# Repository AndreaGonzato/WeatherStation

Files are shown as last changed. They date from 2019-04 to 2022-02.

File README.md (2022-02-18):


# Weather Station
Weather Station is an Arduino project.

## Main Components
 * clock
 * date keeper
 * digital thermometer
 * digital humidity sensor
 * alarm clock
 
## Electronic Components
This is the complete list of all the electronic components that I used for this project:
* [1] Arduino Mega 2560  (you can't use the Arduino Uno because you don't have too many digital pins)
* [1] breadboard (63x10) 
* [1] DHT11 humidity and temperature (digital sensor) 																
	https://www.amazon.it/gp/product/B00L11IISS/ref=ppx_yo_dt_b_asin_title_o06_s00?ie=UTF8&psc=1
* [1] OLED display (128 * 32)  
	https://www.amazon.it/gp/product/B07D9H83R4/ref=ppx_yo_dt_b_asin_title_o05_s00?ie=UTF8&psc=1
* [1] 7-segments display (4 digits, common cathode)
* [2] 7-segments display (1 digit, common cathode)
* [1] passive buzzer  	
	https://www.amazon.it/gp/product/B071DFX4W2/ref=ppx_yo_dt_b_asin_title_o04_s00?ie=UTF8&psc=1
* [3] buttons
* [7] resistors 220 Ohm
* [3] resistors 1k Ohm
* [50/55] Jumper Wires M/M
* [8] Jumper Wires M/F

## Usage
Install these library on your Arduino environment:
* SevSeg  			https://github.com/DeanIsMe/SevSeg
* Adafruit_GFX  	https://github.com/adafruit/Adafruit-GFX-Library
* Adafruit_SSD1306	https://github.com/adafruit/Adafruit_SSD1306
* DHT				https://github.com/adafruit/DHT-sensor-library
* Adafruit_Sensor  	https://github.com/adafruit/Adafruit_Sensor

Open the file Code/Code.ino using Arduino IDE, compile and upload on your Arduino and then connect all the components like the following schema.

Then to controll the weather station/clock you have three buttons and they work like almost every watch.
In this schema the leftmost one is the SET button, in the middle there is the MINUS one and further to the right there is the PLUS one.
To scroll through menus you can press both of them PLUS or MINUS.
For setting a particular activity you need to press a long on the SET button; to deactivate the alarm just press the SET button in the alarm menu.

## Schema
This is one possible schema for this project:
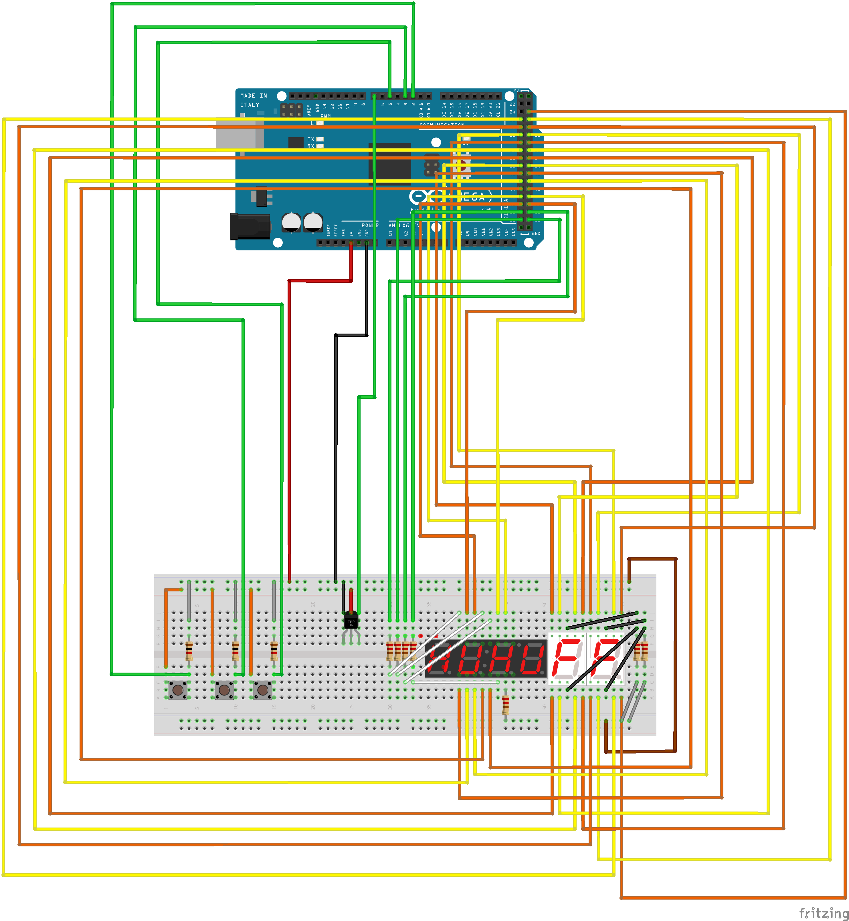
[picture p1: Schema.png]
Scema schema


Note that in this schema there isn't the connection of: passive buzzer and OLED display.
But this two connections are very easy and depends a lot on the components you held.

## Image
This is a photo of my project
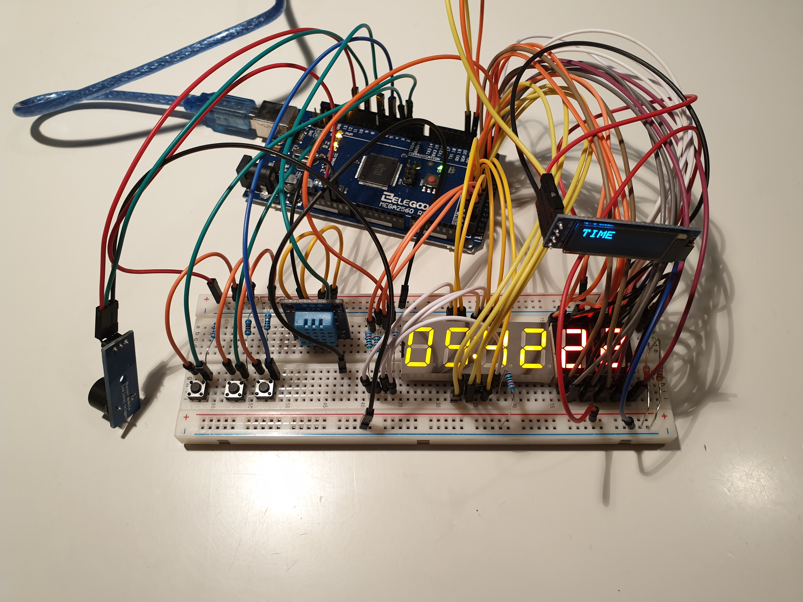
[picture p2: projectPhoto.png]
project photo


## Project Files
**Code** and **Code_No_OOP** folders are two realization of the same project.
If you want all the latest features I recommend to use **Code**.

Last final commit of **Code_No_OOP** was on Apr 18, 2019 and at that time this folder name was "ArduinoCode".

## Hardware & Arduino
The connection protocol used between the display and the Arduino is the I2C.

In Arduino loop function you can't add some delay, because otherwise libraries doesn't work correctly.

The dht11 sensor reads by default the data (temperature and humidity) every 20 seconds. This is to avoid excessive slowdowns to the system.

## Precision
I estimate that the clock loses approximately one second per day.

## Remark
The date format is: dd/mm/yy

## Future developments
The project is not fully completed yet.
Next features to develop:
* new alarm clock melodies
* new timer mode
* new stopwatch mode
* introduction of a barometer sensor and a new mode to read his status 
* introduction of some beep sound during setting mode
* new storage system of weather data on micro sd and a software for having a complete report on PC

## Warnings
The system is not fully tested.

The system after 4,294,967,295 milliseconds ≃ 49 days could crash due to overflow (not tested yet).

## Credits
All the software is open source and developed by Andrea Gonzato

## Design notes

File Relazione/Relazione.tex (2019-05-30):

\documentclass[paper=a4, fontsize=10pt]{scrartcl}

\usepackage{amsmath}
\usepackage[italian]{babel}
\usepackage{tabularx,ragged2e,booktabs,caption} % for table title
\setlength{\parskip}{0.5em} % for paragraph spacing
\DeclareOldFontCommand{\bf}{\normalfont\bfseries}{\mathbf} %declare \bf command in scrartcl

\pagenumbering{gobble} % remove the number of pages

\usepackage{graphicx} % per aggiungere figure/foto

\usepackage{sectsty} % Allows customizing section commands
\allsectionsfont{\normalfont\scshape} % Make all sections, the default font and small caps

%%
\usepackage[utf8]{inputenc}
\newcommand{\approxtext}[1]{\ensuremath{\stackrel{\text{#1}}{\approx}}}
%% now i can add a comment on top of “equal” and “approximate” symbols

\newcommand{\horrule}[1]{\rule{\linewidth}{#1}} % Create horizontal rule command with 1 argument of height

\title{	
\normalfont \normalsize 
\textsc{Universit\`a degli Studi di Trieste - Dipartimento di Ingegneria e Architettura \\ Ingegneria elettronica e informatica - Applicazioni informatiche} \\ [25pt] % Your university, school and/or department name(s)
\horrule{0.5pt} \\[0.4cm] % Thin top horizontal rule
\huge \textbf{Relazione progetto Reti Logiche\\ Weather Station}  \\ % The assignment title
\horrule{2pt} \\[0.5cm] % Thick bottom horizontal rule
}

\author{Andrea Gonzato} % Your name

\date{\normalsize 30 Maggio 2019} % Today's date or a custom date

\setlength{\parindent}{0cm}

\begin{document}
\maketitle % Print the title

\pagebreak

\tableofcontents

\pagebreak

\section{Introduzione}
La relazione riguarda il progetto di Arduino svolto per il corso di reti logiche, tenuto dal professor Marsi dell'Università di Trieste.

\section{Scopo del progetto}
Lo scopo del progetto "Weather Station", come suggerisce il nome, è quello di realizzare una stazione meteorologica amatoriale. L'obiettivo principale è di poter visualizzare la temperatura e l'umidità attuale. Funzionalità secondarie richieste sono: la possibilità di poter leggere l'ora, la data e di poter utilizzare la stazione anche come sveglia. Inoltre è previsto che data, ora e sveglia siano regolabili e che questa sia disattivabile.

\subsection{Descrizione per l'utilizzo}
Per controllare la stazione meteorologica ci sono tre pulsanti: \textit{SET}, \textbf{+}, \textbf{-}.
Il funzionamento ricorda molto l'utilizzo dei classici orologi da polso digitali. Dunque per poter scorrere tutte le funzionalità si utilizzano i pulsanti \textbf{+} e \textbf{-}, mentre per impostare la data, l'ora e la sveglia bisogna tenere premuto, per un secondo, il pulsante \textit{SET}; dopodiché per la regolazione si usano gli analoghi pulsanti,  \textbf{+} e \textbf{-}; invece per passare ad impostare il campo successivo o per attivare/disattivare la sveglia bisogna premere il pulsante \textit{SET} una singola volta.

\subsection{Specifiche}
Il progetto esige come prima specifica che l'orologio non necessiti di una regolazione più di una volta al mese. 
Si richiede quindi la sincronizzazione con un orologio affidabile e dopo 24 ore ci dev'essere una differenza non superiore a un secondo.

La seconda specifica, sui dati meteo, chiede un errore inferiore ad 1 grado Celsius per la temperatura e 2 punti percentuali per l'umidità.

\subsection{Risultato ottenuto}
Nella figura \ref{fig:progettoFoto} si può vedere la realizzazione del progetto completo.

Tutte le specifiche per la realizzazione finale del progetto sono state rispettate.

Nel complesso il sistema si può ritenere funzionante, stabile e facile all'uso.

\begin{figure}
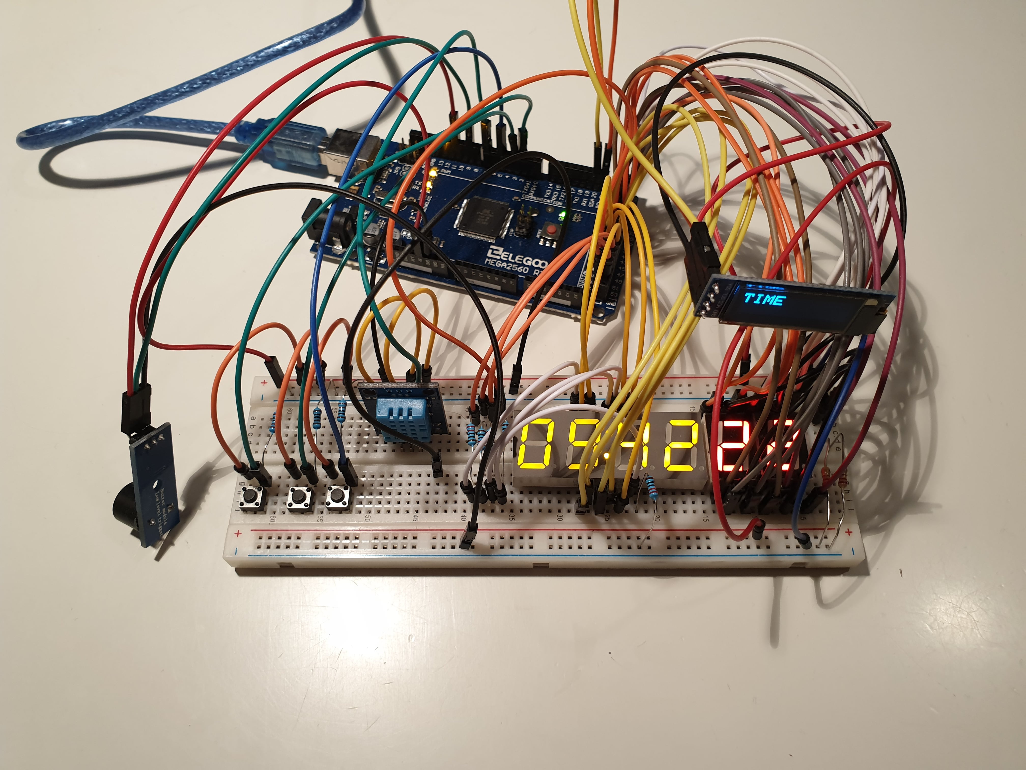
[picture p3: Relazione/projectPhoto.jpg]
  
  \caption{una immagine del progetto}
  \label{fig:progettoFoto}
\end{figure}

\section{Realizzazione}
Il progetto è stato realizzato tra Marzo 2019 e Maggio 2019.\\

\subsection{Metodo usato}
In una prima fase, reperiti i componenti si sono eseguiti una serie di test per comprendere l'utilizzo e le capacità dei singoli.

Nella seconda fase, momento in cui è iniziata la vera realizzazione del progetto, la metodologia adottata si è ispirata al paradigma AGILE. Seguendo questa metodologia si aggiungono funzionalità, una alla volta, passando ciclicamente da una fase di progettazione a una di sviluppo per poi passare ai test e verificare la correttezza delle implementazioni eseguite.

\begin{figure}
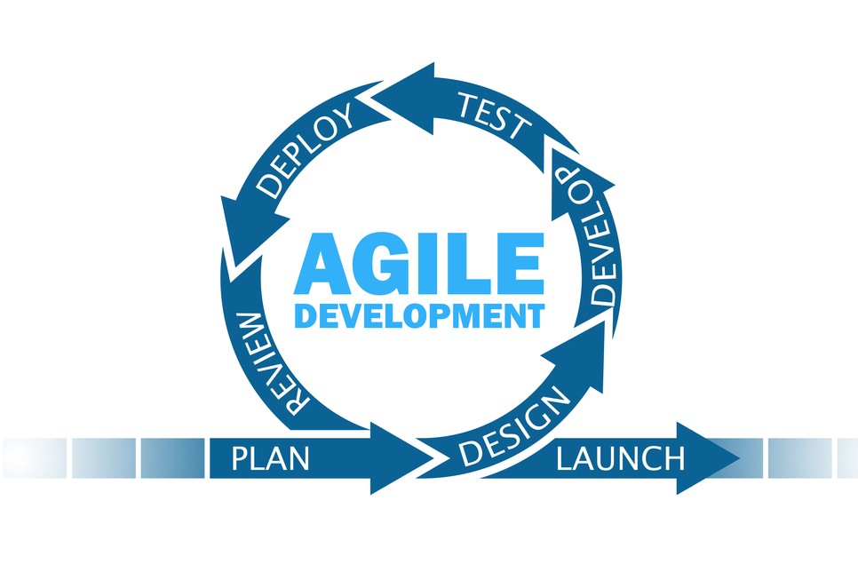
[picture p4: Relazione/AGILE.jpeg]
  
  \caption{paradigma AGILE}
  \label{fig:agile1}
\end{figure}
    
La figura \ref{fig:agile1}
illustra bene il paradigma adottato.

Nell'ultima fase del progetto, una volta implementate gran parte delle funzionalità, bisogna ristrutture il codice, creando una nuova versione strutturata ad oggetti, per poter avere un codice più leggibile ed uniforme.

\pagebreak

\subsection{Struttura della programmazione ad oggetti implementata}
Di seguito viene fornita una breve descrizione di come è stato strutturato ad oggetti il progetto.

Tutti gli oggetti vengono creati nel file \textit{Code/code.ino} e per ogni classe viene implementato un solo oggetto, a parte per la classe \textit{Button} dove ne vengono creati tre. I metodi "principali" di ogni classe si chiamano \textit{update()} e in tali metodi i vari oggetti comunicano tra di loro, i cambiamenti registrati durante il ciclo di esecuzione della funzione \textit{loop()}.

Le classi implementate sono:

\begin{itemize}
\item MyTime: una classe che contiene tutte le variabili temporali e scandisce nel tempo l'evoluzione del sistema. Questa classe serve, per esempio, per l'attivazione dell'allarme della sveglia.

\item Mode: una classe che gestisce e aggiorna il sistema informandolo su cosa bisogna visualizzare sui display a 7 segmenti. Nella stazione meteo ci sono 5 dati fondamentali da far vedere all'utente che sono: il tempo, la data, la temperatura, l'umidità e l'orario al quale è impostata la sveglia. Ma si noti che per questioni progettuali solo uno alla volta di questi dati può essere visualizzato sui display.

\item Button: una classe che gestisce tutte le attività che iniziano alla pressione di un pulsante, per esempio, aggiorna il sistema comunicando che durante un settaggio si è premuto un pulsante per far aumentare le ore dell'orologio. Questa classe è in continua comunicazione con MyTime e Mode.

\item ControllSingleDigitDisplay: una classe che si occupa di visualizzare i dati richiesti sui 2 display a 7 segmenti 1 digit.
\end{itemize}

\subsection{Componenti utilizzati}
Questa è una lista completa del materiale utilizzato
\begin{itemize}
\item Arduino Mega 2560
\item breadboard (63x10)
\item sensore digitale DHT11 per rilevare temperatura e umidità
\item schermo OLED (risoluzione: 128*32)
\item display 7 segmenti (4 digits, catodo comune)
\item 2 display 7 segmenti (1 digit, catodo comune)
\item cicalino (buzzer passivo)
\item 3 bottoni
\item 7 resistenze da 220 Ohm
\item 3 resistenze da 1k Ohm
\item 50/55 cavi elettrici M/M
\item 8 cavi elettrici M/F
\end{itemize}

Si osservi che per la realizzazione di questo progetto non è sufficiente un Arduino Uno, perché da come si vede in Figura \ref{fig:schema1}, sono necessarie 34 connessioni digitali.
\subsection{Schema}
In fondo alla relazione si può osservare la figura \ref{fig:schema1} che indica lo schema utilizzato per il progetto.

Si nota che nello schema non sono presenti le connessioni del cicalino e dello schermo OLED. Queste sono particolarmente semplici e intuitive. Se si vuole usare il codice del progetto, i pin del cicalino I/O e VCC vanno connessi rispettivamente a i pin Arduino 9 e 11.

\pagebreak

\subsection{Strumenti usati}
I principali strumenti utilizzati sono: l'ambiente Arduino e Fritzing come software per disegnare gli schemi elettronici.\\
Nel codice del progetto sono presenti come librerie esterne:
\begin{itemize}
\item \textit{SevSeg}
\item \textit{DHT}
\item \textit{Adafruit Sensor}
\item \textit{Adafruit GFX}
\item \textit{Adafruit SSD1306}
\end{itemize}

\textit{SevSeg} è utile per "scrivere" sul display a 7 segmenti 4 digits; mentre \textit{DHT} e \textit{Adafruit Sensor} servono per leggere i dati dal sensore che rilevava la temperatura e l'umidità; infine  le ultime due librerie permettono di utilizzare lo schermo OLED. 

\subsection{Scelte progettuali e difficoltà}
Una delle scelte progettuali fondamentali è quella di decidere come far scandire il tempo al sistema:
Una possibilità consiste nell'acquistare un modulo RTC appositamente designato per queste attività. In alternativa si può far scandire il tempo direttamente ad Arduino. Infatti si può creare una variabile \textit{long unsigned} che si incrementa al passare di ogni millisecondo. Se si sceglie quest'ultima realizzazione, che è quella attuata nel progetto, si evita l'acquisto di un modulo, ma il prezzo da pagare è un potenziale crash di sistema. Infatti, teoricamente, dopo 4,294,967,295 millisecondi, cioè circa 49 giorni, la variabile arriva in \textit{overflow}. Questo avvenimento non è ancora stato testato, ma si raccomanda di resettare la stazione prima dello scadere del quarantottesimo giorno dall'avvio.

La difficoltà più grande, che si incontra durante il progetto, è sicuramente la gestione e la sincronizzazione dei display a 7 segmenti. Nel progetto di partenza, l'idea era quella di realizzare un sistema di visualizzazione dati, utilizzando due display a 7 segmenti con 4 digits, quindi poter disporre di un totale di 8 digits. Il problema di questa realizzazione è che la libreria \textit{SevSeg} utilizzata non supporta l'opportunità di comandare più display contemporaneamente. Il progetto finale si realizza con l'implementazione di un display 4 digits, controllato dalla libreria, affiancato da due display sigle digit, controllati senza libreria, ma con comandi standard \textit{digitalWrite()} di Arduino. Questa realizzazione rende l'aggiornamento dei display non uniforme e non ottimizzata, infatti ad ogni esecuzione dell'\textit{loop()}, ciclicamente un solo digit del display, composto da quattro digit, si aggiorna mentre entrambi i display single digit si aggiornano contemporaneamente. In futuro, si potrebbe migliorare questa non uniformità nell'illuminazione dei display, ma attualmente non si ritiene fondamentale.

Come protocollo di comunicazione tra il display OLED e Arduino viene usato il protocollo $I^{2}C$. La motivazione di questa scelta risiede dal fatto, che l'Arduino Mega 2560 possiede due pin, addetti a tale scopo.

L'utilizzo della libreria \textit{SevSeg} porta che all'interno del \textit{loop()} non può essere inserito alcun ritardo di qualunque tipo. Se si verificassero questi ritardi, il display a 7 segmenti 4 digits inizierebbe a sfarfallare. A causa di questa problematica il sensore di umidità e temperatura rileva i dati non in maniera continuata, ma esclusivamente ogni 20 secondi. Questo avviene perché se no si verificherebbero dei ritardi nell'\textit{loop()}. Infatti, se si osserva bene il display, ogni 20 secondi, c'è un piccolo sfarfallamento, ma non è particolarmente fastidioso.

\section{Sviluppi futuri}
I prossimi sviluppi per questo progetto riguardano aspetti secondari.
Di seguito vengono elencate alcuni possibili sviluppi futuri per il progetto:
\begin{itemize}
\item introduzione di nuove melodie più piacevoli per la sveglia.

\item introduzione di una nuova funzionalità che permetta l'uso della stazione anche come cronometro.

\item introduzione di una nuova funzionalità che permetta l'uso della stazione anche come timer.

\item implementazione di un sensore che rilevi la pressione (barometro) e di una funzionalità che permetta di vedere il suo stato attuale.

\item introduzione di effetti sonori, durante le attività di settaggio degli strumenti.

\item implementazione di un sistema di memorizzazione che scriva i dati meteorologici (temperatura, umidità e pressione) in una scheda sd, permettendo di creare degli storici sui dati rilevati.

\end{itemize}

\section{Rilascio materiale}
Tutto il materiale di questo progetto è rilasciato con licenza open source ed è reperibile al seguente sito:
\textit{https://github.com/AndreaGonzato/WeatherStation}

In questa pagina è possibile trovare anche la vecchia versione del codice non strutturato ad oggetti. Tale versione, chiamata \textit{"Code No OOP"}, non supporta le ultime funzionalità come ad esempio la sveglia. Questa versione può rilevarsi utile per chi intende contribuire a questo progetto, ma non ha molta famigliarità con la programmazione ad oggetti.

\section{Conclusioni}
Sicuramente il progetto non è ne perfetto ne completo, ma nel complesso si può definire un prototipo funzionante.

\section{Sitografia}

Le librerie utilizzate sono reperibili ai seguenti siti:
\begin{itemize}
\item https://github.com/DeanIsMe/SevSeg
\item https://github.com/adafruit/Adafruit-GFX-Library
\item https://github.com/adafruit/Adafruit\_SSD1306
\item https://github.com/adafruit/DHT-sensor-library
\item https://github.com/adafruit/Adafruit\_Sensor
\end{itemize}

Altri siti dove sono state lette guide e tutorial sono:
\begin{itemize}
\item https://www.arduino.cc/en/Tutorial/BuiltInExamples
\item https://create.arduino.cc/projecthub
\item http://www.circuitbasics.com/arduino-7-segment-display-tutorial/
\item https://overvolt.tech/sensori/3
\item http://www.associazionemarconi.com/calcolo/codice\_resistenze\_elettriche\_5.html
\end{itemize}

\section{Dichiarazione finale}
Tutto il lavoro è stato svolto da me in completa autonomia.

\begin{figure}
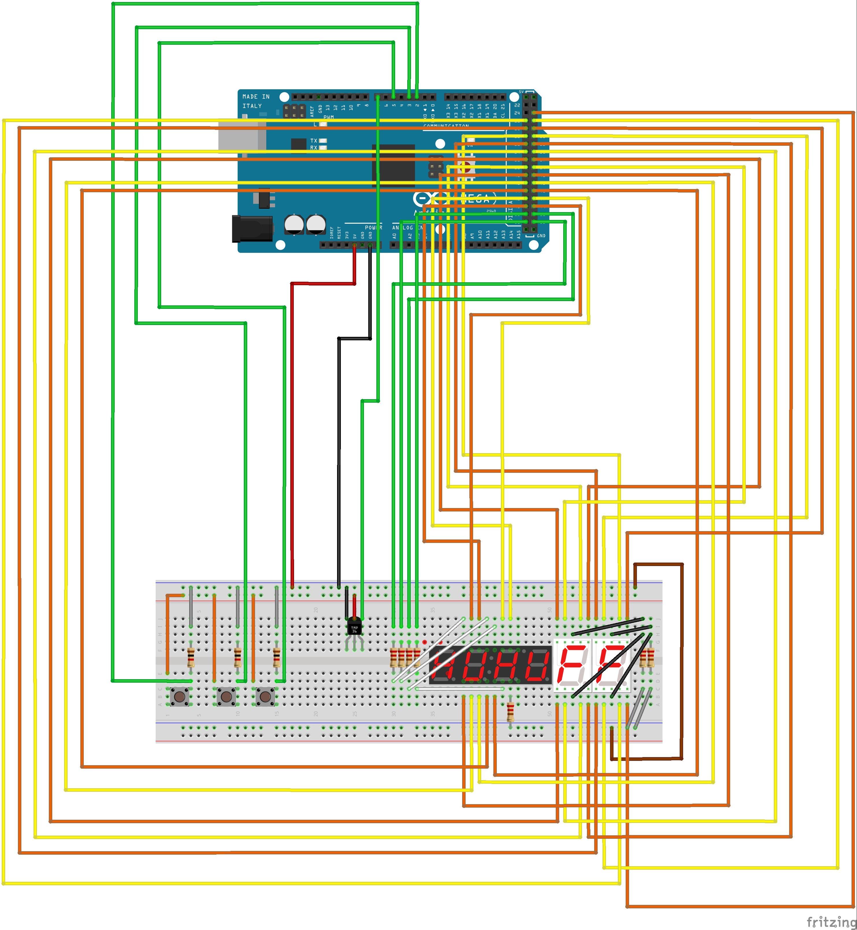
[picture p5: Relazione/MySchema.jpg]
  
  \caption{Schema del circuito}
  \label{fig:schema1}
\end{figure}

\end{document}

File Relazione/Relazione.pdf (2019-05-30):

Universita degli Studi di Trieste - Dipartimento di Ingegneria e `

Architettura

Ingegneria elettronica e informatica - Applicazioni informatiche

# Relazione progetto Reti Logiche Weather Station

## Andrea Gonzato

30 Maggio 2019

Indice

### 1 Introduzione

### 2 Scopo del progetto

2.1 Descrizione per l’utilizzo |
2.2 Specifiche |
2.3 Risultato ottenuto |

### 3 Realizzazione

3.1 Metodo usato |
3.2 Struttura della programmazione ad oggetti implementata |
3.3 Componenti utilizzati |
3.4 Schema |
3.5 Strumenti usati |
3.6 Scelte progettuali e difficolt`a |

### 4 Sviluppi futuri

### 5 Rilascio materiale

### 6 Conclusioni

### 7 Sitografia

### 8 Dichiarazione finale

1 Introduzione

La relazione riguarda il progetto di Arduino svolto per il corso di reti logiche, tenuto dal professor Marsi dell’Universit`a di Trieste.

2 Scopo del progetto

Lo scopo del progetto ”Weather Station”, come suggerisce il nome, `e quello di realizzare una stazione meteorologica amatoriale. L’obiettivo principale `e di poter visualizzare la temperatura e l’umidit`a attuale. Funzionalit`a secondarie richieste sono: la possibilit`a di poter leggere l’ora, la data e di poter utilizzare la stazione anche come sveglia. Inoltre `e previsto che data, ora e sveglia siano regolabili e che questa sia disattivabile.

2.1 Descrizione per l’utilizzo

Per controllare la stazione meteorologica ci sono tre pulsanti: SET, +, -. Il funzionamento ricorda molto l’utilizzo dei classici orologi da polso digitali. Dunque per poter scorrere tutte le funzionalit`a si utilizzano i pulsanti + e -, mentre per impostare la data, l’ora e la sveglia bisogna tenere premuto, per un secondo, il pulsante SET; dopodich´e per la regolazione si usano gli analoghi pulsanti, + e -; invece per passare ad impostare il campo successivo o per attivare/disattivare la sveglia bisogna premere il pulsante SET una singola volta.

2.2 Specifiche

Il progetto esige come prima specifica che l’orologio non necessiti di una regolazione pi`u di una volta al mese. Si richiede quindi la sincronizzazione con un orologio affidabile e dopo 24 ore ci dev’essere una differenza non superiore a un secondo.

La seconda specifica, sui dati meteo, chiede un errore inferiore ad 1 grado Celsius per la temperatura e 2 punti percentuali per l’umidit`a.

2.3 Risultato ottenuto

Nella figura 1 si pu`o vedere la realizzazione del progetto completo.

Tutte le specifiche per la realizzazione finale del progetto sono state rispettate.

Nel complesso il sistema si pu`o ritenere funzionante, stabile e facile all’uso.


Figura 1: una immagine del progetto

3 Realizzazione

Il progetto `e stato realizzato tra Marzo 2019 e Maggio 2019.

3.1 Metodo usato

In una prima fase, reperiti i componenti si sono eseguiti una serie di test per comprendere l’utilizzo e le capacit`a dei singoli.

Nella seconda fase, momento in cui `e iniziata la vera realizzazione del progetto, la metodologia adottata si `e ispirata al paradigma AGILE. Seguendo questa metodologia si aggiungono funzionalit`a, una alla volta, passando ciclicamente da una fase di progettazione a una di sviluppo per poi passare ai test e verificare la correttezza delle implementazioni eseguite.

La figura 2 illustra bene il paradigma adottato.

Nell’ultima fase del progetto, una volta implementate gran parte delle funzionalit`a, bisogna ristrutture il codice, creando una nuova versione strutturata ad oggetti, per poter avere un codice pi`u leggibile ed uniforme.


Figura 2: paradigma AGILE

3.2 Struttura della programmazione ad oggetti

implementata

Di seguito viene fornita una breve descrizione di come `e stato strutturato ad oggetti il progetto.

Tutti gli oggetti vengono creati nel file Code/code.ino e per ogni classe viene implementato un solo oggetto, a parte per la classe Button dove ne vengono creati tre. I metodi ”principali” di ogni classe si chiamano update() e in tali metodi i vari oggetti comunicano tra di loro, i cambiamenti registrati durante il ciclo di esecuzione della funzione loop().

Le classi implementate sono:

- MyTime: una classe che contiene tutte le variabili temporali e scandisce nel tempo l’evoluzione del sistema. Questa classe serve, per esempio, per l’attivazione dell’allarme della sveglia.
- Mode: una classe che gestisce e aggiorna il sistema informandolo su cosa bisogna visualizzare sui display a 7 segmenti. Nella stazione meteo ci sono 5 dati fondamentali da far vedere all’utente che sono: il tempo, la data, la temperatura, l’umidit`a e l’orario al quale `e impostata la sveglia. Ma si noti che per questioni progettuali solo uno alla volta di questi dati pu`o essere visualizzato sui display.
- Button: una classe che gestisce tutte le attivit`a che iniziano alla pressione di un pulsante, per esempio, aggiorna il sistema comunicando che durante un settaggio si `e premuto un pulsante per far aumentare le ore dell’orologio. Questa classe `e in continua comunicazione con MyTime e Mode.
- ControllSingleDigitDisplay: una classe che si occupa di visualizzare i dati richiesti sui 2 display a 7 segmenti 1 digit.

3.3 Componenti utilizzati

Questa `e una lista completa del materiale utilizzato

- Arduino Mega 2560
- breadboard (63x10)
- sensore digitale DHT11 per rilevare temperatura e umidit`a
- schermo OLED (risoluzione: 128*32)
- display 7 segmenti (4 digits, catodo comune)
- 2 display 7 segmenti (1 digit, catodo comune)
- cicalino (buzzer passivo)
- 3 bottoni
- 7 resistenze da 220 Ohm
- 3 resistenze da 1k Ohm
- 50/55 cavi elettrici M/M
- 8 cavi elettrici M/F

Si osservi che per la realizzazione di questo progetto non `e sufficiente un Arduino Uno, perch´e da come si vede in Figura 3, sono necessarie 34 connessioni digitali.

3.4 Schema

In fondo alla relazione si pu`o osservare la figura 3 che indica lo schema utilizzato per il progetto.

Si nota che nello schema non sono presenti le connessioni del cicalino e dello schermo OLED. Queste sono particolarmente semplici e intuitive. Se si vuole usare il codice del progetto, i pin del cicalino I/O e VCC vanno connessi rispettivamente a i pin Arduino 9 e 11.

3.5 Strumenti usati

I principali strumenti utilizzati sono: l’ambiente Arduino e Fritzing come software per disegnare gli schemi elettronici.
Nel codice del progetto sono presenti come librerie esterne:
- SevSeg
- DHT
- Adafruit Sensor
- Adafruit GFX
- Adafruit SSD1306

SevSeg `e utile per ”scrivere” sul display a 7 segmenti 4 digits; mentre DHT e Adafruit Sensor servono per leggere i dati dal sensore che rilevava la temperatura e l’umidit`a; infine le ultime due librerie permettono di utilizzare lo schermo OLED.

3.6 Scelte progettuali e difficolta`

Una delle scelte progettuali fondamentali `e quella di decidere come far scandire il tempo al sistema: Una possibilit`a consiste nell’acquistare un modulo RTC appositamente designato per queste attivit`a. In alternativa si pu`o far scandire il tempo direttamente ad Arduino. Infatti si pu`o creare una variabile long unsigned che si incrementa al passare di ogni millisecondo. Se si sceglie quest’ultima realizzazione, che `e quella attuata nel progetto, si evita l’acquisto di un modulo, ma il prezzo da pagare `e un potenziale crash di sistema. Infatti, teoricamente, dopo 4,294,967,295 millisecondi, cio`e circa 49 giorni, la variabile arriva in overflow. Questo avvenimento non `e ancora stato testato, ma si raccomanda di resettare la stazione prima dello scadere del quarantottesimo giorno dall’avvio.

La difficolt`a pi`u grande, che si incontra durante il progetto, `e sicuramente la gestione e la sincronizzazione dei display a 7 segmenti. Nel progetto di partenza, l’idea era quella di realizzare un sistema di visualizzazione dati, utilizzando due display a 7 segmenti con 4 digits, quindi poter disporre di un totale di 8 digits. Il problema di questa realizzazione `e che la libreria SevSeg utilizzata non supporta l’opportunit`a di comandare pi`u display contemporaneamente. Il progetto finale si realizza con l’implementazione di un display 4 digits, controllato dalla libreria, affiancato da due display sigle digit, controllati senza libreria, ma con comandi standard digitalWrite() di Arduino. Questa realizzazione rende l’aggiornamento dei display non uniforme e non ottimizzata, infatti ad ogni esecuzione dell’loop(), ciclicamente un solo digit del display, composto da quattro digit, si aggiorna mentre entrambi i display single digit si aggiornano contemporaneamente. In futuro, si potrebbe migliorare questa non uniformit`a nell’illuminazione dei display, ma attualmente non si ritiene fondamentale.

Come protocollo di comunicazione tra il display OLED e Arduino viene usato il protocollo I

2C. La motivazione di questa scelta risiede dal fatto, che l’Arduino Mega 2560 possiede due pin, addetti a tale scopo.

L’utilizzo della libreria SevSeg porta che all’interno del loop() non pu`o essere inserito alcun ritardo di qualunque tipo. Se si verificassero questi ritardi, il display a 7 segmenti 4 digits inizierebbe a sfarfallare. A causa di questa problematica il sensore di umidit`a e temperatura rileva i dati non in maniera continuata, ma esclusivamente ogni 20 secondi. Questo avviene perch´e se no si verificherebbero dei ritardi nell’loop(). Infatti, se si osserva bene il display, ogni 20 secondi, c’`e un piccolo sfarfallamento, ma non `e particolarmente fastidioso.

4 Sviluppi futuri

I prossimi sviluppi per questo progetto riguardano aspetti secondari. Di seguito vengono elencate alcuni possibili sviluppi futuri per il progetto:

- introduzione di nuove melodie pi`u piacevoli per la sveglia.
- introduzione di una nuova funzionalit`a che permetta l’uso della stazione anche come cronometro.
- introduzione di una nuova funzionalit`a che permetta l’uso della stazione anche come timer.
- implementazione di un sensore che rilevi la pressione (barometro) e di una funzionalit`a che permetta di vedere il suo stato attuale.
- introduzione di effetti sonori, durante le attivit`a di settaggio degli strumenti.
- implementazione di un sistema di memorizzazione che scriva i dati meteorologici (temperatura, umidit`a e pressione) in una scheda sd, permettendo di creare degli storici sui dati rilevati.

5 Rilascio materiale

Tutto il materiale di questo progetto `e rilasciato con licenza open source ed `e reperibile al seguente sito: https://github.com/AndreaGonzato/WeatherStation

In questa pagina `e possibile trovare anche la vecchia versione del codice non strutturato ad oggetti. Tale versione, chiamata ”Code No OOP”, non supporta le ultime funzionalit`a come ad esempio la sveglia. Questa versione pu`o rilevarsi utile per chi intende contribuire a questo progetto, ma non ha molta famigliarit`a con la programmazione ad oggetti.

6 Conclusioni

Sicuramente il progetto non `e ne perfetto ne completo, ma nel complesso si pu`o definire un prototipo funzionante.

7 Sitografia

Le librerie utilizzate sono reperibili ai seguenti siti:

- https://github.com/DeanIsMe/SevSeg
- https://github.com/adafruit/Adafruit-GFX-Library
- https://github.com/adafruit/Adafruit SSD1306
- https://github.com/adafruit/DHT-sensor-library
- https://github.com/adafruit/Adafruit Sensor

Altri siti dove sono state lette guide e tutorial sono:

- https://www.arduino.cc/en/Tutorial/BuiltInExamples
- https://create.arduino.cc/projecthub
- http://www.circuitbasics.com/arduino-7-segment-display-tutorial/
- https://overvolt.tech/sensori/3
- http://www.associazionemarconi.com/calcolo/codice resistenze elettriche 5.html

8 Dichiarazione finale

Tutto il lavoro `e stato svolto da me in completa autonomia.

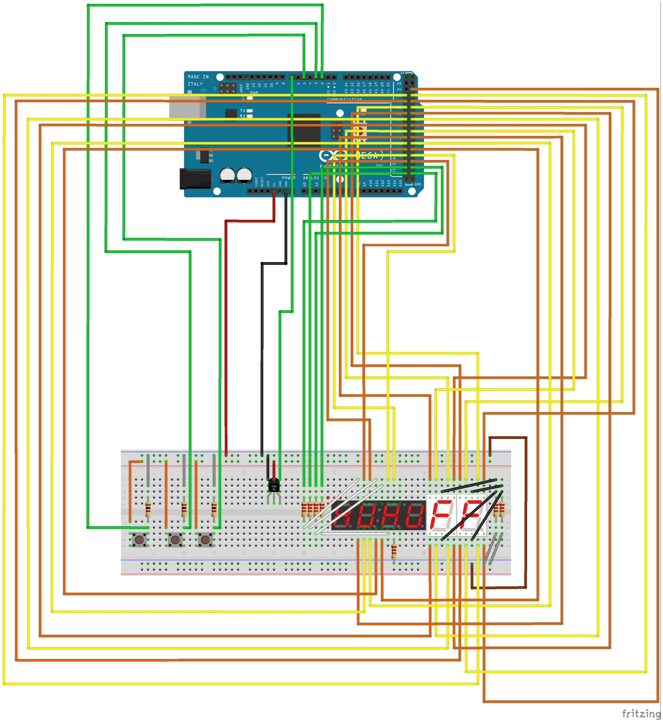
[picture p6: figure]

Figura 3: Schema del circuito

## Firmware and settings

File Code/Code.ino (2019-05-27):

//library for humidity and temperature sensor
#include <DHT.h>
const int sensorPin = 7;
DHT dht(sensorPin, DHT11);

//library for OLED display
#include <SPI.h>
#include <Wire.h>
#include <Adafruit_GFX.h>
#include <Adafruit_SSD1306.h>
#define SCREEN_WIDTH 128 // OLED display width, in pixels
#define SCREEN_HEIGHT 32 // OLED display height, in pixels
// Declaration for an SSD1306 display connected to I2C (SDA, SCL pins)
#define OLED_RESET     4 // Reset pin # (or -1 if sharing Arduino reset pin)
Adafruit_SSD1306 display(SCREEN_WIDTH, SCREEN_HEIGHT, &Wire, OLED_RESET);

//library for 7-segments display
#include "SevSeg.h"
SevSeg sevseg;

const int allarmPinIO= 9;
const int allarmPin5V= 11;
const int alarmFrequency = 380;

//7-segments 4 digit display
const int seg_a_4_digits = 49;
const int seg_b_4_digits = 47;
const int seg_c_4_digits = 44;
const int seg_d_4_digits = 42;
const int seg_e_4_digits = 41;
const int seg_f_4_digits = 48;
const int seg_g_4_digits = 45;
const int seg_p_4_digits = 43; //point  .
const int seg_dp_4_digits = 46; //double point  :

//display digits of:
const int d1 = 53; //Digit 1
const int d2 = 52; //Digit 2
const int d3 = 51; //Digit 3
const int d4 = 50; //Digit 4

#include "src/MyTime.h"
MyTime myTime = MyTime(allarmPinIO, allarmPin5V, alarmFrequency);

#include "src/Mode.h"
Mode mode = Mode();

#include "src/Button.h"
Button setButton = Button(2, "SET");
Button minButton = Button(3, "MIN");
Button plusButton = Button(5, "PLUS");

#include "src/controllSingleDigitDisplay.h"
controllSingleDigitDisplay singleDigitDisplay = controllSingleDigitDisplay();

//sensor dht var:
float temperature;
int humidity;

unsigned long lastSamplingSensor = 0;
int samplingSensorInterval = 20000;

void setup(){
    //declare pin:
    //allarm pin:
    pinMode(allarmPinIO, OUTPUT);
    pinMode(allarmPin5V, OUTPUT); 
    
    //display (4 digits)
    pinMode(seg_a_4_digits, OUTPUT);
    pinMode(seg_b_4_digits, OUTPUT);
    pinMode(seg_c_4_digits, OUTPUT);
    pinMode(seg_d_4_digits, OUTPUT);
    pinMode(seg_e_4_digits, OUTPUT);
    pinMode(seg_f_4_digits, OUTPUT);
    pinMode(seg_g_4_digits, OUTPUT);
    pinMode(seg_p_4_digits, OUTPUT);
    pinMode(seg_dp_4_digits, OUTPUT);
    
    pinMode(d1, OUTPUT);
    pinMode(d2, OUTPUT);
    pinMode(d3, OUTPUT);
    pinMode(d4, OUTPUT);

    //SET UP SEVSEG LIBRARY
    byte numDigits = 4;
    byte digitPins[] = {d1, d2, d3, d4};
    byte segmentPins[] = {seg_a_4_digits, seg_b_4_digits, seg_c_4_digits, seg_d_4_digits, seg_e_4_digits, seg_f_4_digits, seg_g_4_digits, seg_p_4_digits};
    bool resistorsOnSegments = true; 
    bool updateWithDelaysIn = true;
    byte hardwareConfig = COMMON_CATHODE; 
    sevseg.begin(hardwareConfig, numDigits, digitPins, segmentPins, resistorsOnSegments);
    sevseg.setBrightness(90);
    digitalWrite(seg_dp_4_digits, HIGH);  // set the two points on :
  
    Serial.begin(9600);

    //start sensor dht ativity
    dht.begin();
    
    //OLED SET UP
    if(!display.begin(SSD1306_SWITCHCAPVCC, 0x3C)) { // Address 0x3C for 128x32
      Serial.println(F("SSD1306 allocation failed"));
      for(;;); // Don't proceed, loop forever
    }
    OLEDisplayText(mode.getActiveMode());
    display.display();

    temperature = dht.readTemperature();
    humidity = dht.readHumidity();
}


void loop(){
    myTime.update(&mode);
    setButton.update(&mode, &myTime);
    minButton.update(&mode, &myTime);
    plusButton.update(&mode, &myTime);

    unsigned long currentTime = millis(); // update current time

    if(currentTime - lastSamplingSensor > samplingSensorInterval){
      lastSamplingSensor = currentTime;
      temperature = dht.readTemperature();  // update current temperature
      humidity = dht.readHumidity();        // update current humidity
    }
    
    //display on 7-segments
    displayOn7Segments();

    //display on OLED
    if(mode.getUpdateOLED()){
        String myString = mode.getActiveMode();
        OLEDisplayText(myString);
        display.display();
    }
    mode.setUpdateOLED(false);

}


void displayOn7Segments(){
    //this method is used to display on 7-segment display all the info
    
    int numToDisplayOnSingleDigit = -1;
    // if at the end this var will be negative, then will not display nothing
    
    if(mode.getActiveMode() == "TIME"){
        digitalWrite(seg_dp_4_digits, HIGH);  // set the two points on :
        
        if(!mode.getSettingActivity() || mode.getDisplayWhatAreYouSetting()){
            //display all
            int myTimeToDisplay = myTime.getMyHours() * 100 + myTime.getMyMinutes() ;
            sevseg.setNumber(myTimeToDisplay, 4);
            sevseg.refreshDisplay();
            numToDisplayOnSingleDigit = myTime.getMySec();
        }else{
            switch (mode.getIndexSubMenu()){
                case 1: //do not show hours    
                    update7SegDiplayTime(-1, myTime.getMyMinutes());           
                    numToDisplayOnSingleDigit = myTime.getMySec();
                    break;
                case 2: //do not show minutes    
                    update7SegDiplayTime(myTime.getMyHours(), -1);           
                    numToDisplayOnSingleDigit = myTime.getMySec();
                    break;
                case 3: //do not show seconds    
                    update7SegDiplayTime(myTime.getMyHours(), myTime.getMyMinutes());           
                    numToDisplayOnSingleDigit = -1;
                    break;
            }
        }     
    }
    
    if(mode.getActiveMode() == "DATE"){
        digitalWrite(seg_dp_4_digits, LOW);  // set the two points off :
        if(!mode.getSettingActivity() || mode.getDisplayWhatAreYouSetting()){
            //display all
            update7SegDiplayDate(myTime.getMyDay(), myTime.getMyMonth());
            numToDisplayOnSingleDigit = myTime.getMyYear();
        }else{
            switch (mode.getIndexSubMenu()){
                case 1: //do not show day
                    update7SegDiplayDate(myTime.getMyDay()*-1, myTime.getMyMonth());
                    numToDisplayOnSingleDigit = myTime.getMyYear();
                    break;
                case 2: //do not show month
                    update7SegDiplayDate(myTime.getMyDay(), myTime.getMyMonth()*-1);
                    numToDisplayOnSingleDigit = myTime.getMyYear();
                    break;
               case 3: //do not show month
                    update7SegDiplayDate(myTime.getMyDay(), myTime.getMyMonth());
                    numToDisplayOnSingleDigit = myTime.getMyYear()*-1;
                    break;
            }
        }
    }
    
    if(mode.getActiveMode() == "DEGREES"){
        digitalWrite(seg_dp_4_digits, LOW);  // set the two points off :
        int myTemperatureToDisplay = (int)(temperature) ;
        sevseg.setNumber(myTemperatureToDisplay, 0);
        sevseg.refreshDisplay();
        int myDecimalTemperature = (int)((temperature*100) - (myTemperatureToDisplay*100));
        numToDisplayOnSingleDigit = abs(myDecimalTemperature);
    }
    
    if(mode.getActiveMode() == "HUMIDITY"){
        digitalWrite(seg_dp_4_digits, LOW);  // set the two points off :
        sevseg.setNumber(humidity);
        sevseg.refreshDisplay();
    }
    
    if(mode.getActiveMode() == "ALARM OFF" || mode.getActiveMode() == "ALARM ON" ){
        digitalWrite(seg_dp_4_digits, HIGH);  // set the two points on :
        
        if(!mode.getSettingActivity() || mode.getDisplayWhatAreYouSetting()){
            int myTimeAlarmToDisplay = myTime.getMyHoursAlarm() * 100 + myTime.getMyMinutesAlarm() ;
            sevseg.setNumber(myTimeAlarmToDisplay, 4);
            sevseg.refreshDisplay();
            numToDisplayOnSingleDigit = myTime.getMySecAlarm();
        }else{
            switch (mode.getIndexSubMenu()){
                case 1: //do not show hours    
                    update7SegDiplayTime(-1, myTime.getMyMinutesAlarm());           
                    numToDisplayOnSingleDigit = myTime.getMySecAlarm();
                    break;
                case 2: //do not show minutes    
                    update7SegDiplayTime(myTime.getMyHoursAlarm(), -1);           
                    numToDisplayOnSingleDigit = myTime.getMySecAlarm();
                    break;
                case 3: //do not show seconds    
                    update7SegDiplayTime(myTime.getMyHoursAlarm(), myTime.getMyMinutesAlarm());           
                    numToDisplayOnSingleDigit = -1;
                    break; 
            }
        }
    }
    
    singleDigitDisplay.myUpdate(numToDisplayOnSingleDigit);  //update single digut display
    
}


void OLEDisplayText(String text) {
    //this method is used to overwrite/display info on the OLED display
    
    display.clearDisplay();
    
    display.setTextSize(2);             // Normal 1:1 pixel scale
    display.setTextColor(WHITE);        // Draw white text
    display.setCursor(0,0);             // Start at top-left corner
    
    display.println(text);              // Display the text 
}


void update7SegDiplayDate(int day, int month){
    //this method is used to display day & month on the 7-segments display
     
    int d1 = day % 10;
    int d2 = (day - d1) / 10;
    char c2 = (char)d1;
    char c1 = (char)d2;
    int m1 = month % 10;
    int m2 = (month - m1) / 10;
    char c4 = (char)m1;
    char c3 = (char)m2;
    
    char str[5] = {' ', ' ','.',' ', ' '};
    if(day>= 0){
        str[0] = c1+'0';
        str[1] = c2+'0';
    }
    if(month>= 0){
        str[3] = c3+'0';
        str[4] = c4+'0';
    }
    sevseg.setChars(str);
    sevseg.refreshDisplay();
}


void update7SegDiplayTime(int hour, int minutes){
    //this method is used to display hour & minutes on the 7-segments display
    
    int d1 = hour % 10;
    int d2 = (hour - d1) / 10;
    char c2 = (char)d1;
    char c1 = (char)d2;
    int m1 = minutes % 10;
    int m2 = (minutes - m1) / 10;
    char c4 = (char)m1;
    char c3 = (char)m2;
    
    char str[4] = {' ', ' ',' ', ' '};
    if(hour>= 0){
        str[0] = c1+'0';
        str[1] = c2+'0';
    }
    if(minutes>= 0){
        str[2] = c3+'0';
        str[3] = c4+'0';
    }
    
    sevseg.setChars(str);
    sevseg.refreshDisplay();
}

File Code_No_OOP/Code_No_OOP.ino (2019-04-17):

//library for 7-segments display
#include "SevSeg.h"
SevSeg sevseg; 

//library for OLED display
#include <SPI.h>
#include <Wire.h>
#include <Adafruit_GFX.h>
#include <Adafruit_SSD1306.h>

//library for humidity and temperature sensor
#include <DHT.h>
const int sensorPin = 7;
DHT dht(sensorPin, DHT11);


#define SCREEN_WIDTH 128 // OLED display width, in pixels
#define SCREEN_HEIGHT 32 // OLED display height, in pixels

// Declaration for an SSD1306 display connected to I2C (SDA, SCL pins)
#define OLED_RESET     4 // Reset pin # (or -1 if sharing Arduino reset pin)
Adafruit_SSD1306 display(SCREEN_WIDTH, SCREEN_HEIGHT, &Wire, OLED_RESET);

/////////////////////////////////////////////////////////////////

//CONSTANTS
const long longPressTime = 1000;    // it is just a const, that indicate how many millisec is a long click for the system
const long samplingSensorInterval = 30000;
unsigned long lastSamplingSensor= 0;
// DIGITAL PIN

//DISPLAY

//7-segments 4 digit display
const int seg_a_4_digits = 49;
const int seg_b_4_digits = 47;
const int seg_c_4_digits = 44;
const int seg_d_4_digits = 42;
const int seg_e_4_digits = 41;
const int seg_f_4_digits = 48;
const int seg_g_4_digits = 45;
const int seg_p_4_digits = 43; //point  .
const int seg_dp_4_digits = 46; //double point  :

//display digits of:
const int d1 = 53; //Digit 1
const int d2 = 52; //Digit 2
const int d3 = 51; //Digit 3
const int d4 = 50; //Digit 4

// single digit display 1 & 2
const int seg_a[] = {38, 30};
const int seg_b[] = {37, 29};
const int seg_c[] = {34, 26};
const int seg_d[] = {35, 27};
const int seg_e[] = {36, 28};
const int seg_f[] = {39, 31};
const int seg_g[] = {40, 32};
const int seg_p[] = {33, 25}; 

//BUTTONS pins
const int setButton = 2;
const int minButton = 3;
const int plusButton = 5;


// GLOBAL VARIABLES

//TIME VAR
int sec;
int minutes;
int hours;
int day = 1;
int month = 1;
int year = 19;

//sensor dht var:
float temperature;
int humidity;

unsigned long blinkingTime = 500;

//BUTTON VAR
//variable for reading the Buttons status (true if Botton is press, false if is not press)
boolean setButtonState = false;
boolean minButtonState = false;
boolean plusButtonState = false;

//var that indicate if it is time to display: sec, minutes, hours
//for example when you are setting the clock minutes, evry half second displayMin change value
boolean displaySec = true;
boolean displayMin = true;
boolean displayHours = true;

boolean displayDay = true;
boolean displayMonth = true;
boolean displayYear = true;


//just for the right evulution of the script (I have to find a better way)
boolean avoidIfPlus = true;
boolean avoidIfMin = true;

//variable that indicate if we are setting time of the clock (it happend when the setBotton had a long click)
boolean settingTimeMode = false;
boolean settingDateMode = false;

//variable that indicate what we are setting:
int setingTimeSubMenu = 0;
//Here there is a leggend for how this var work:
/*
 *  0 : we are setting nothing
 *  1 : hors
 *  2 : minutes
 *  3 : sec
 *  4 : we have finished to set evrything, now immidatly go to state 0  (4 --> 0)
 */
int setingDateSubMenu = 0;
//Here there is a leggend for how this var work:
/*
 *  0 : we are setting nothing
 *  1 : day
 *  2 : month
 *  3 : year
 *  4 : we have finished to set evrything, now immidatly go to state 0  (4 --> 0)
 */
int menuActivity = 0;
//Here there is a leggend for how this var work:
/*
 *  -1: go to humidity
 *  0 : time
 *  1 : date
 *  2 : temperature
 *  3 : humidity
 *  4 : go to time
 */

long setButtonTimer = 0;            // var to calcolate how long was the clik on setBotton, it get the inizial time when setBotton was pressed

unsigned long previousTime;  // a var to control/remember when the last second started
unsigned long previousTimeBlink; // the last blink was a this time previousTimeBlink
unsigned long synchronizationTimeInterval = 1000; // 1000 millis = 1 second
boolean displayOn = true;
boolean scrollMenu = false;

void setup(){

  //START TIME
  sec = 0;
  minutes = 0;
  hours = 0;

  //start sensor dht ativity
  dht.begin();
  
  //declare pin:
  //display (4 digits)
  pinMode(seg_a_4_digits, OUTPUT);
  pinMode(seg_b_4_digits, OUTPUT);
  pinMode(seg_c_4_digits, OUTPUT);
  pinMode(seg_d_4_digits, OUTPUT);
  pinMode(seg_e_4_digits, OUTPUT);
  pinMode(seg_f_4_digits, OUTPUT);
  pinMode(seg_g_4_digits, OUTPUT);
  pinMode(seg_p_4_digits, OUTPUT);
  pinMode(seg_dp_4_digits, OUTPUT);

  pinMode(d1, OUTPUT);
  pinMode(d2, OUTPUT);
  pinMode(d3, OUTPUT);
  pinMode(d4, OUTPUT);

  for(int i=0 ; i<2 ; i++){
    pinMode(seg_a[i], OUTPUT);
    pinMode(seg_b[i], OUTPUT);
    pinMode(seg_c[i], OUTPUT);
    pinMode(seg_d[i], OUTPUT);
    pinMode(seg_e[i], OUTPUT);
    pinMode(seg_f[i], OUTPUT);
    pinMode(seg_g[i], OUTPUT);
    pinMode(seg_p[i], OUTPUT);
  }
  

  //declare botton pins
  pinMode(setButton, INPUT);
  pinMode(minButton, INPUT);
  pinMode(plusButton, INPUT);

  //SET UP SEVSEG LIBRARY
  byte numDigits = 4;
  byte digitPins[] = {d1, d2, d3, d4};
  byte segmentPins[] = {seg_a_4_digits, seg_b_4_digits, seg_c_4_digits, seg_d_4_digits, seg_e_4_digits, seg_f_4_digits, seg_g_4_digits, seg_p_4_digits};
  bool resistorsOnSegments = true; 
  bool updateWithDelaysIn = true;
  byte hardwareConfig = COMMON_CATHODE; 
  sevseg.begin(hardwareConfig, numDigits, digitPins, segmentPins, resistorsOnSegments);
  sevseg.setBrightness(90);

  digitalWrite(seg_dp_4_digits, HIGH);  // set the two points on :
  

  Serial.begin(9600);
  
  //OLED SET UP
  if(!display.begin(SSD1306_SWITCHCAPVCC, 0x3C)) { // Address 0x3C for 128x32
    Serial.println(F("SSD1306 allocation failed"));
    for(;;); // Don't proceed, loop forever
  }

  temperature = dht.readTemperature();
  humidity = dht.readHumidity();
  Serial.println(humidity);
  
  //display somthing on OLED display
  OLEDisplayText("TIME");
  display.display();

}
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

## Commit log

2019-04-14 Schema completed
    [Schema.fzz]
2019-04-14 sensor implementation & new Menù
2019-04-14 readable temperature
2019-05-27 final changes 1
    [Schema.fzz]
2022-02-18 add arduino Logo
